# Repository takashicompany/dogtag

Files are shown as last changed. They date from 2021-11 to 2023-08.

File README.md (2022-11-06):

# DogTag

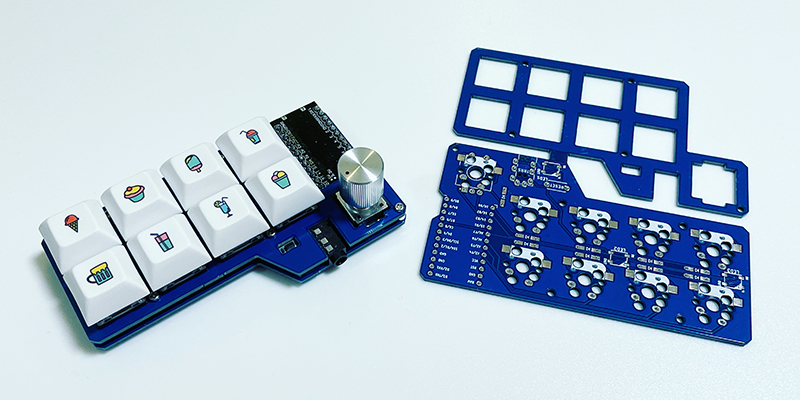
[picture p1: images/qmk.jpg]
dogtag


DogTagは9キーのコンパクトなマクロパッドです。  
100mm x 100mm 以内のPCBから組み立てます。  
リバーシブルに対応しており、2台をTRRSケーブルで接続することで分割型のマクロパッドとしても使用できます。  
その他にもロータリーエンコーダの搭載やMXソケットによるキースイッチの付け替え(ホットスワップ)も可能です。  
LEDによるアンダーグロウも可能です。  

DogTag is a compact macro pad with 9 keys.  
It is assembled from a PCB no larger than 100mm x 100mm.  
It is reversible and can be used as a split macro pad by connecting two units with a TRRS cable.  
Other features include a rotary encoder and MX sockets for hot-swapping of keyswitches.  
LED underglow is also available.  




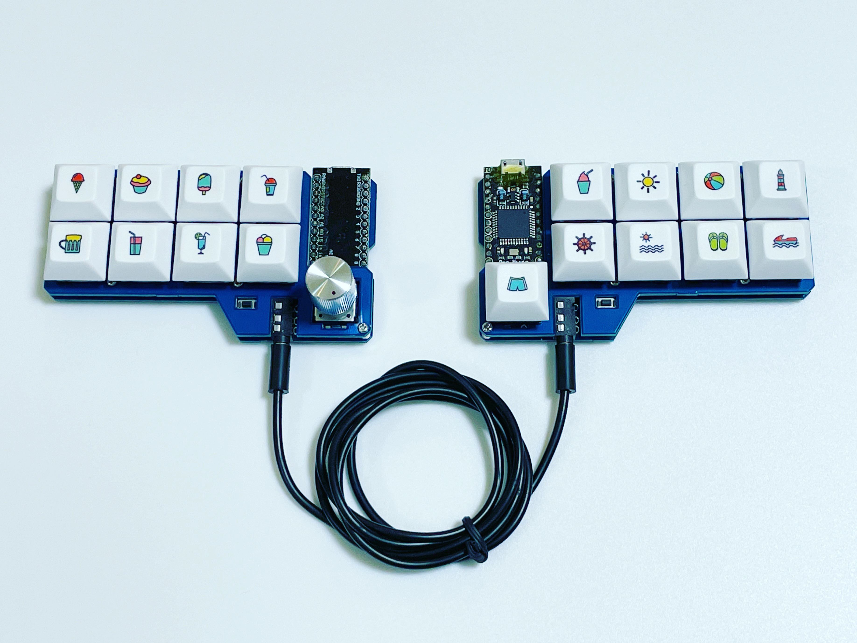
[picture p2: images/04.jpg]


## 必要な部品

### キットに同梱されているもの
|部品|個数|備考|
|:--|:--|:--|
|PCB|1|リードタイプと表面実装のダイオードに対応。|
|ダイオード（リードタイプ)|9||
|m2スペーサー(3.5mm)|5||
|m2ネジ(3mm)|10||
|リセットスイッチ|1||
|TRRSソケット|1||
|滑り止めシール|4||

### 別途用意するもの
|部品|個数|備考|
|:--|:--|:--|
|キースイッチ|9|Cherry MX互換のもの。|
|キーキャップ|9|全て1u。Chery MX互換のもの。|
|Pro Micro|1||
|USBケーブル|1|Pro MicroとPCを接続します。|

### オプション
|部品|個数|備考|
|:--|:--|:--|
|コンスルー|2|Pro Microに取り付けます。|
|MXソケット|9|キースイッチの付け替えが可能になります。|
|ロータリーエンコーダ|1|親指に近いキーにロータリーエンコーダを取り付けることができます。
|LED(SK6812MINI-E)|4|キーボードが光ります。|

## 組み立て方
alt設定 (https://www.youtube.com/watch?v=5uZxdYJqcw4)

以下の組み立て方は左手用になります。
右手側の場合は基板を裏返して組み立ててください。

### 1. トッププレートとPCBを切り離す

トッププレートとPCBが結合しているので、これを切り離します。  
(場合によっては切り離し済みのケースがあります。)  
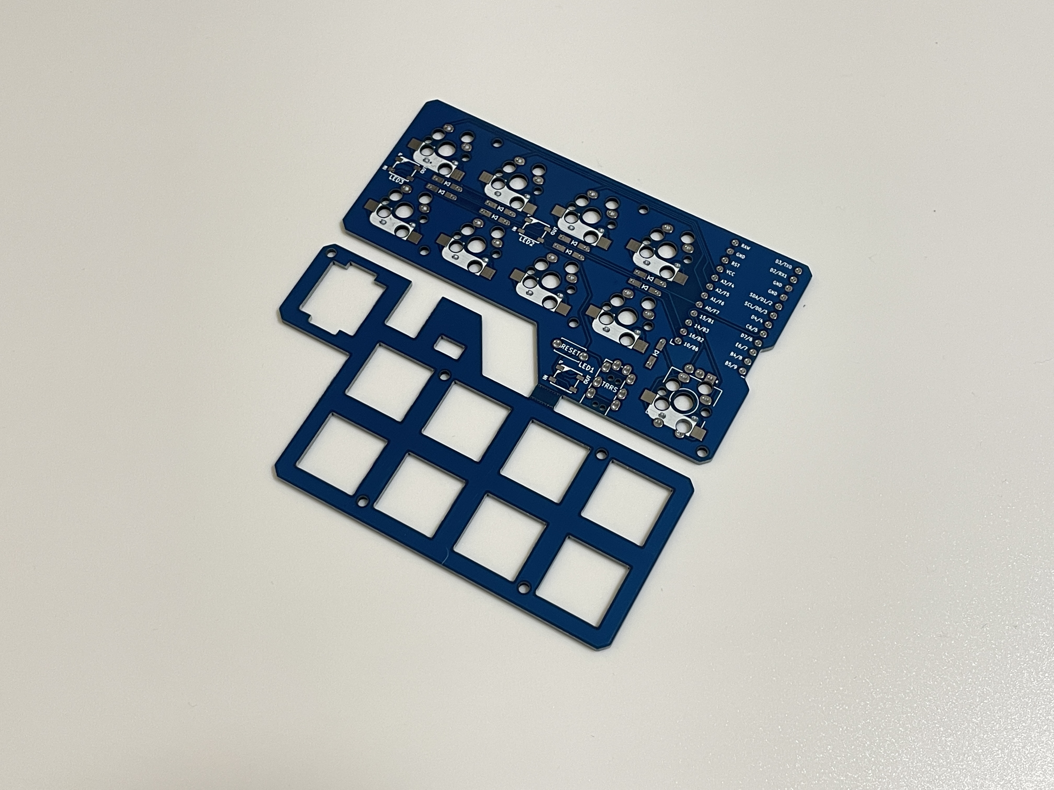
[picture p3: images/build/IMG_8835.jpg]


基板を接続部の折れ線に沿って曲げると切り離せます。  
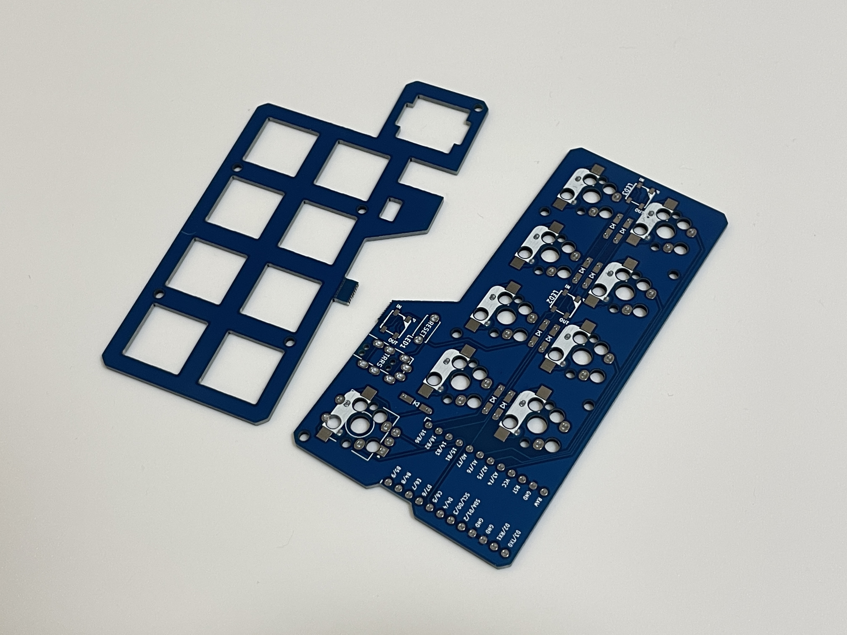
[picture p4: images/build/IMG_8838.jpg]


残った接続部分はペンチなどで折ると取りやすいです。  
折った場所をヤスリがけすると仕上がりがキレイになります。  
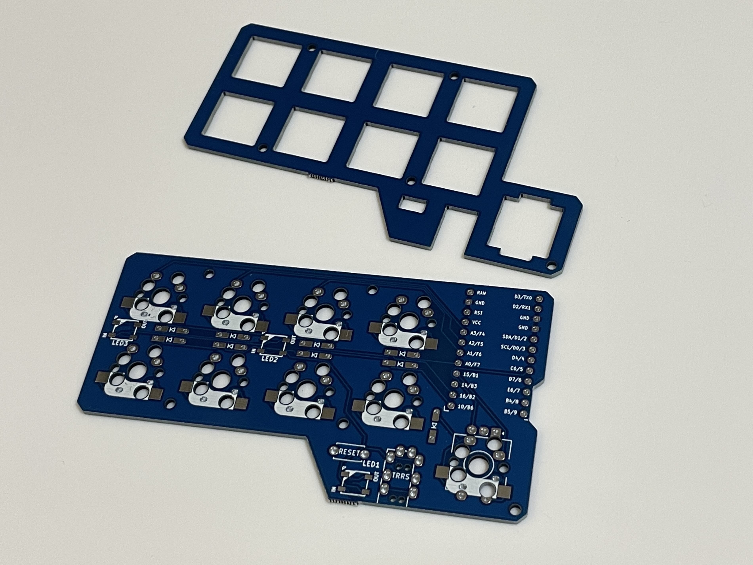
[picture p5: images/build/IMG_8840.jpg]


### 2. ダイオードをはんだ付けする  

ダイオードを取り付けます。  
余談ですが、ダイオードは電流の向きを制御する役割があります。  
自作キーボードでは主にキーが同時に押されたことを検知する役割があります。  
以上のことは知らなくても当キーボードは完成させられますのでご安心ください🙏  
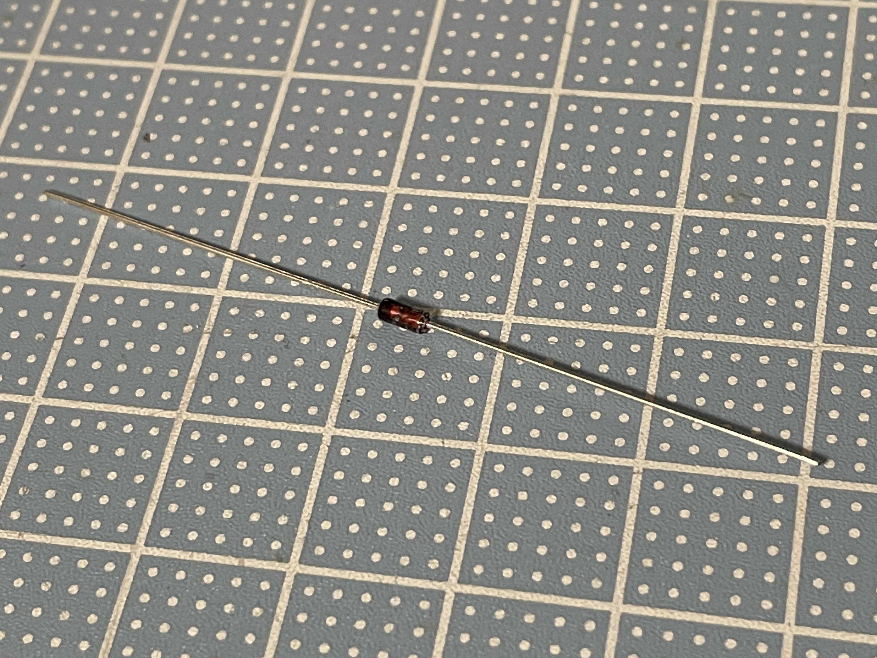
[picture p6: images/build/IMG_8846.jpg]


ダイオードが基板のはんだ付け穴に入るように足を曲げます。  
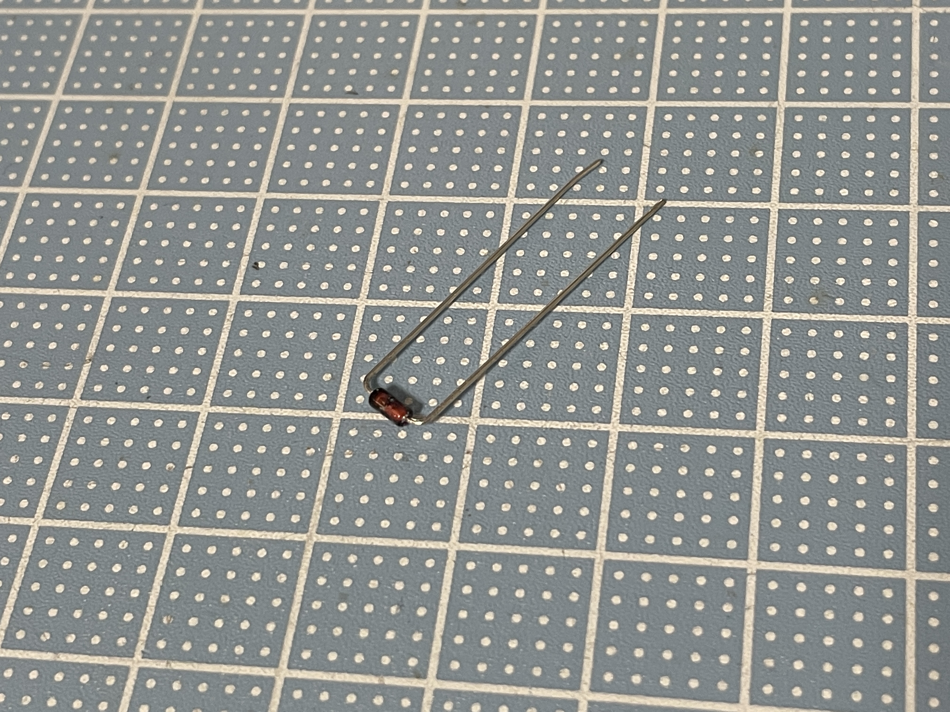
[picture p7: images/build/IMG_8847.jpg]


ダイオードをはんだ付け穴に挿します。  
ダイオードの端の黒い線が、基板の矢印(|◁)側になるようにPCBに挿します。
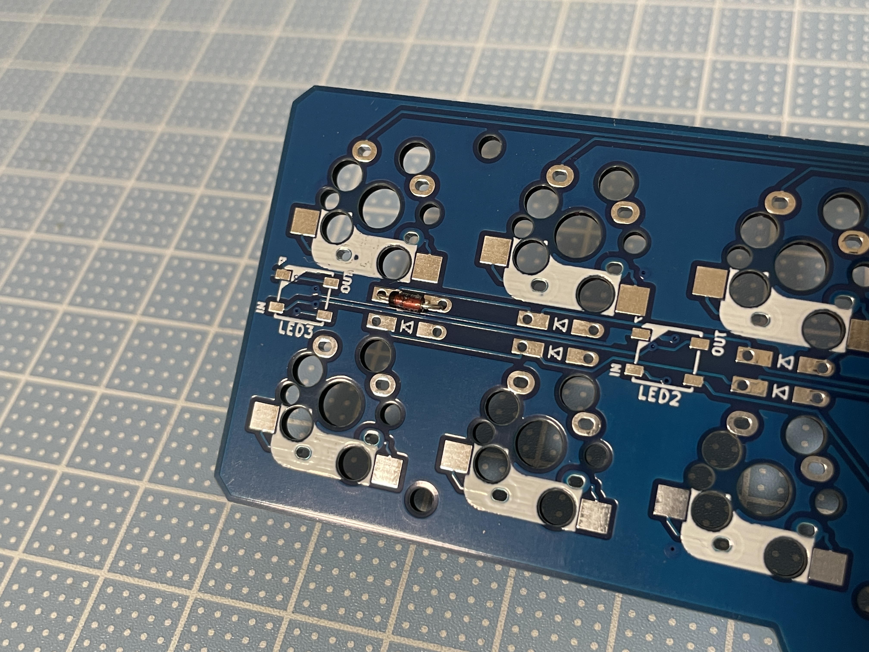
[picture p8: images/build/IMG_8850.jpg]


はんだ付けをするために基板を反対側にします。  
この時、ダイオードの足を少し開くとPCBから抜けづらくなります。  
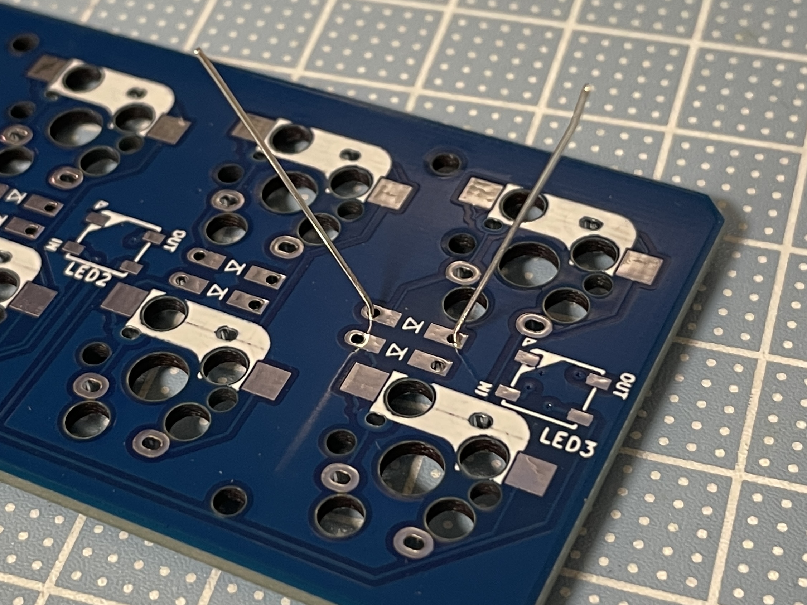
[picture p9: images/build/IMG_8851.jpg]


はんだ付けを行います。  
はんだ付けがはじめての方は[こちら](https://www.youtube.com/watch?v=iCJXT3d4140)の動画を参考に進めるとスムーズに行くかと思います。  
(難しそうなイメージがありますが、要はくっついていれば良いのです)

はんだ付けが済んだら、ニッパーで足を切ります。  
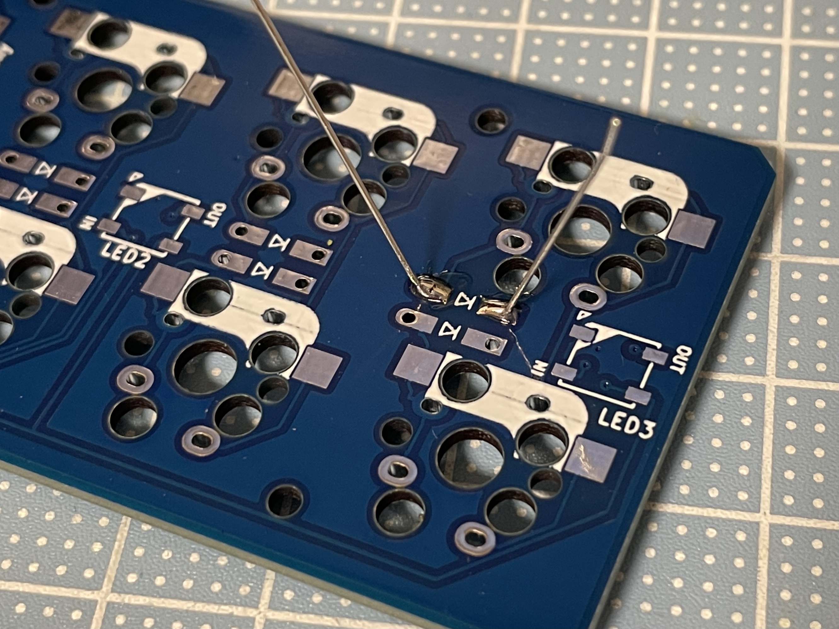
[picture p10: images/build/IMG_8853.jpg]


合計9箇所をはんだ付けします。  
**ダイオードの向きが写真と異なっていないかを確認してください。**
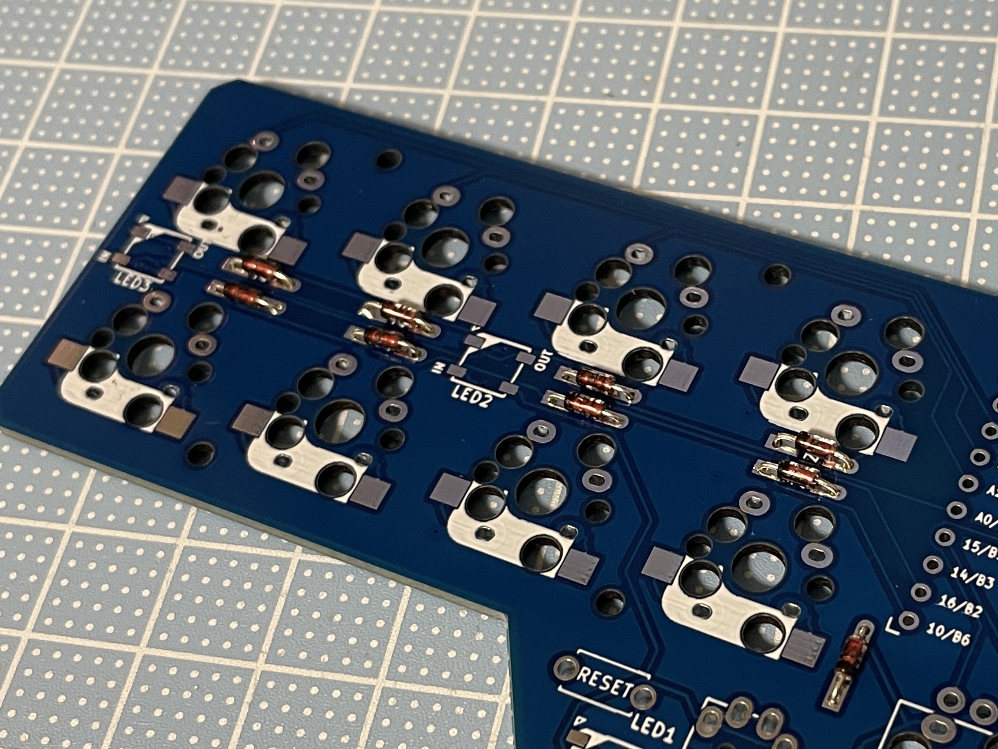
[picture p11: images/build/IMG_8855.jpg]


### 3. リセットスイッチの取り付け

リセットスイッチはファームウェアを書き込む際などに使用します。  
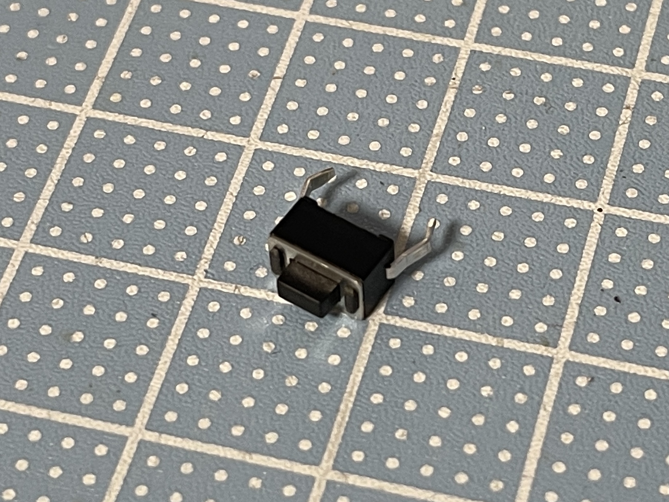
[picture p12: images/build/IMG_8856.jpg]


取り付け位置はキーボードの手前の「RESET」の印刷がされている箇所です。  
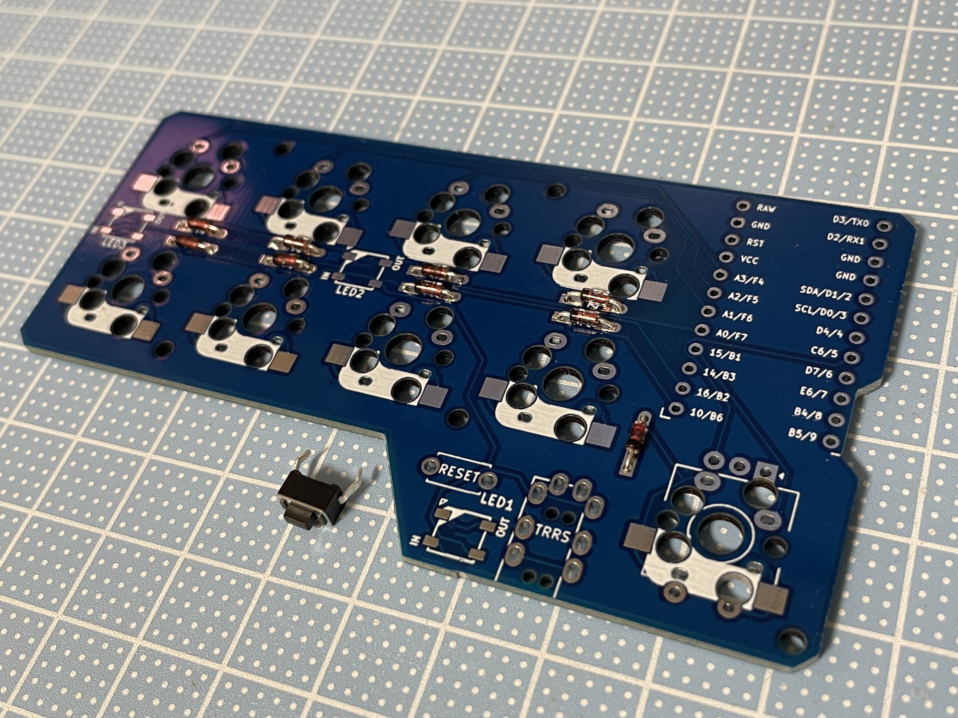
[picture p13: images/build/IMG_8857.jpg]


穴にリセットスイッチの足を挿し込みます。  
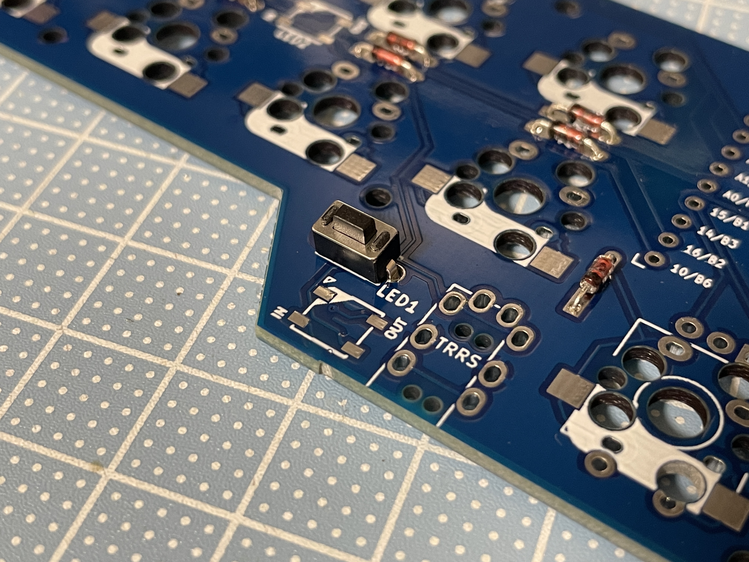
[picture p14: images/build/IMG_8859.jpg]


基板をひっくり返してリセットスイッチの足が穴から出ていることを確認します。   
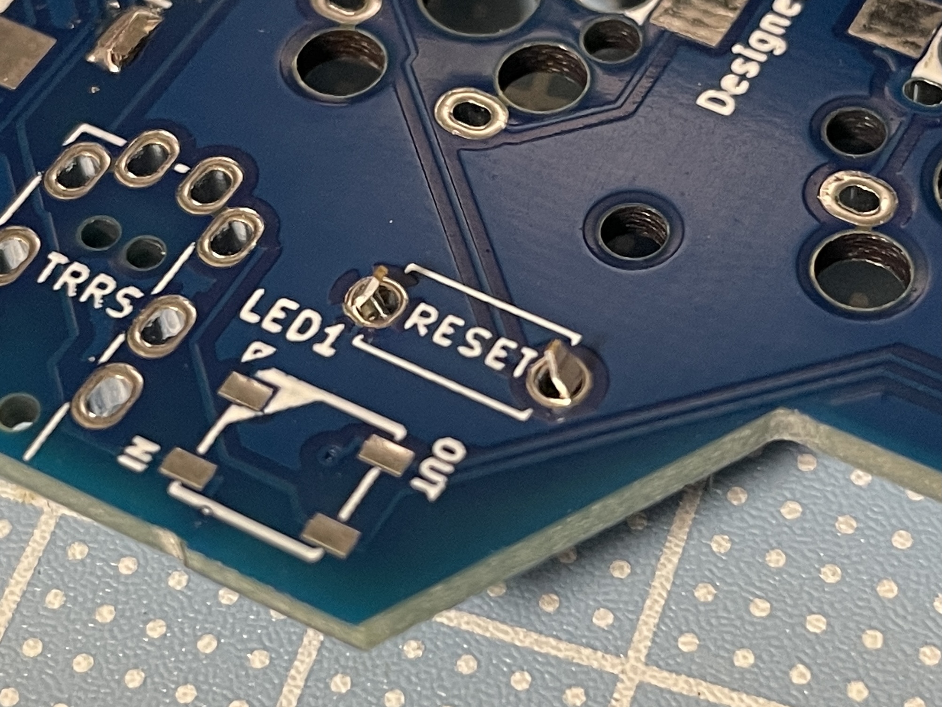
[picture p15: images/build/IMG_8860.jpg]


はんだ付けを行います。  
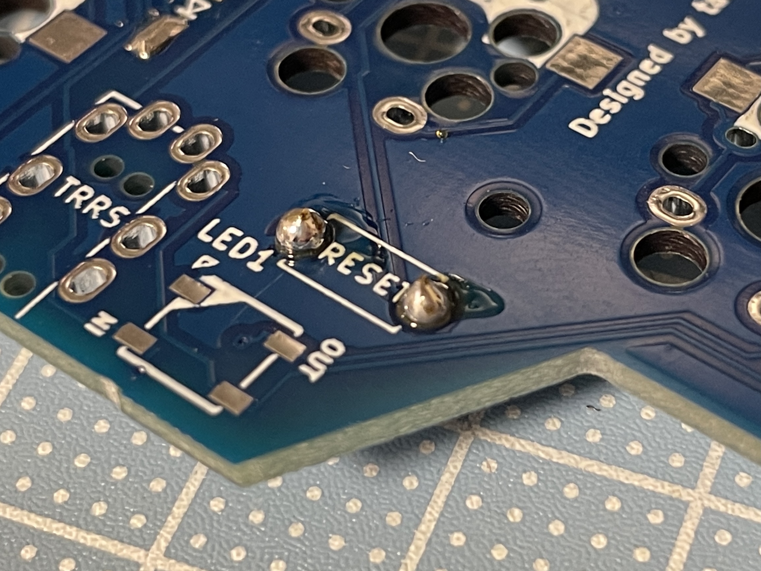
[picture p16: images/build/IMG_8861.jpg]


はんだ付けを済ませたらニッパーなどではんだ付け部分を切り取り、可能な限り平らにするとキーボードが安定しやすくなります。  
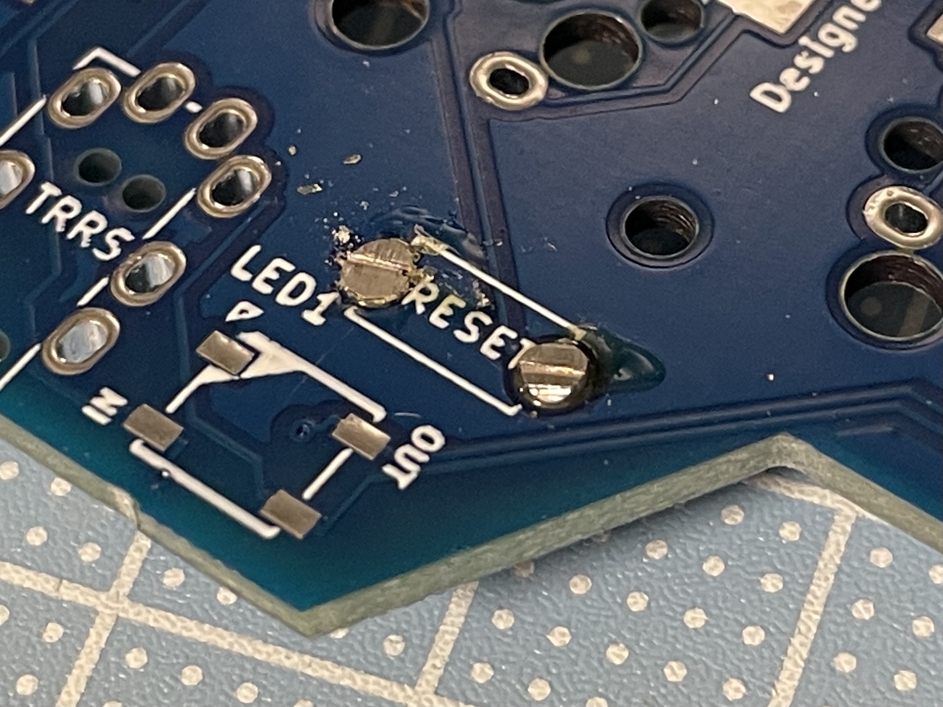
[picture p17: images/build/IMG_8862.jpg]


### 4. TRRSソケットの取り付け

TRRSソケットは、分割キーボードとして利用する場合にキーボード同士を繋げるために使います。  
単体で使う場合は使用しませんが、気が変わって両手分欲しくなっても良いように取り付けましょう笑  
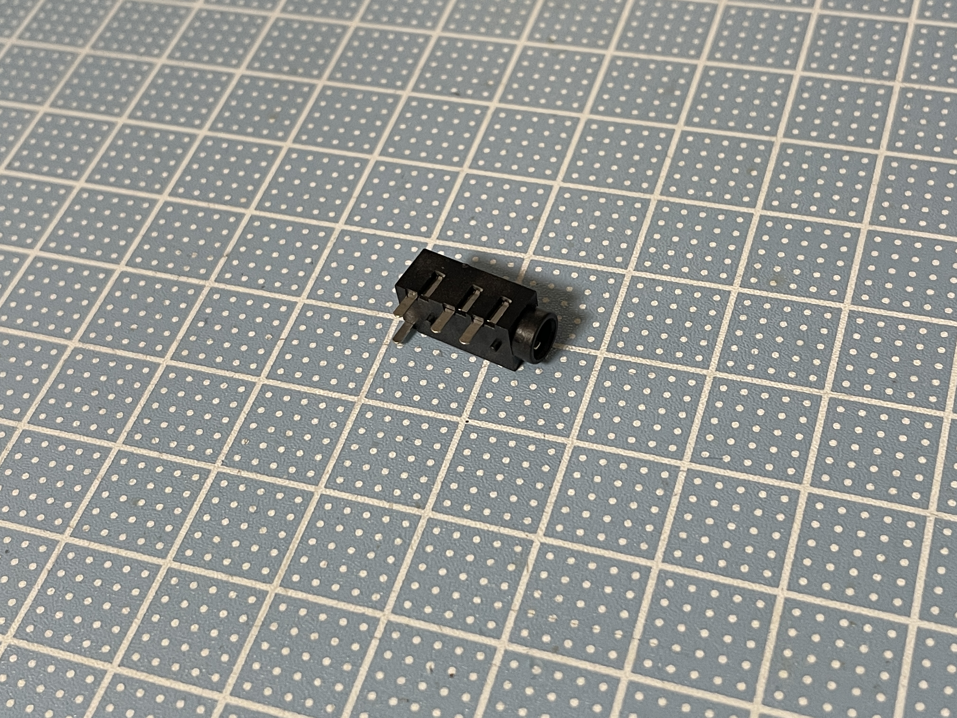
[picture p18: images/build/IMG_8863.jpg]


取り付け位置は、基板手前側の「TRRS」と印刷されている箇所です。
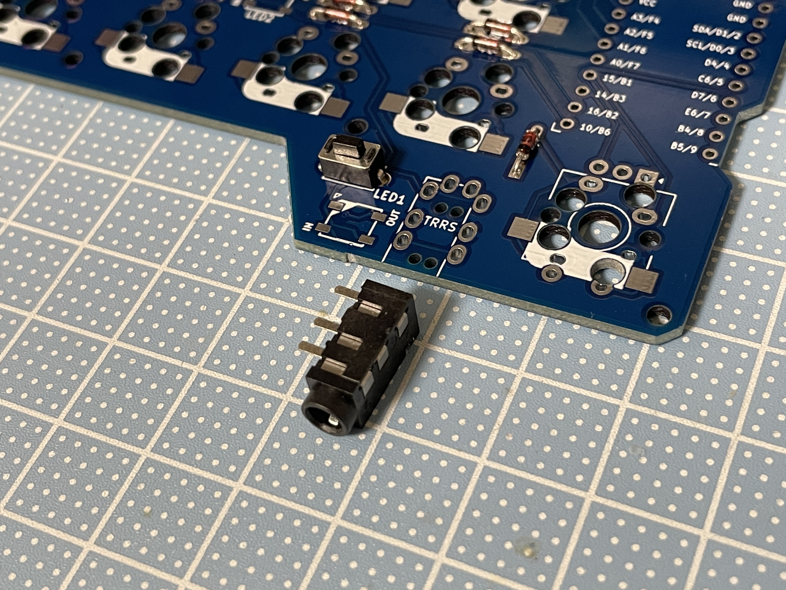
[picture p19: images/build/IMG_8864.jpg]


穴に沿って挿し込みます。  
いくつか穴が余ってしまうのは、右手側で利用する際の穴です。  
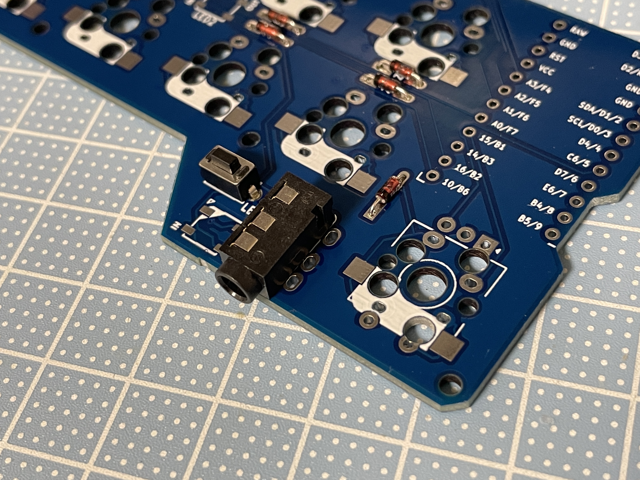
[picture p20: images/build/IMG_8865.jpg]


はんだ付けの際にひっくり返す時にTRRSソケットが抜けてしまう場合は、マスキングテープなどで固定すると良いです。  
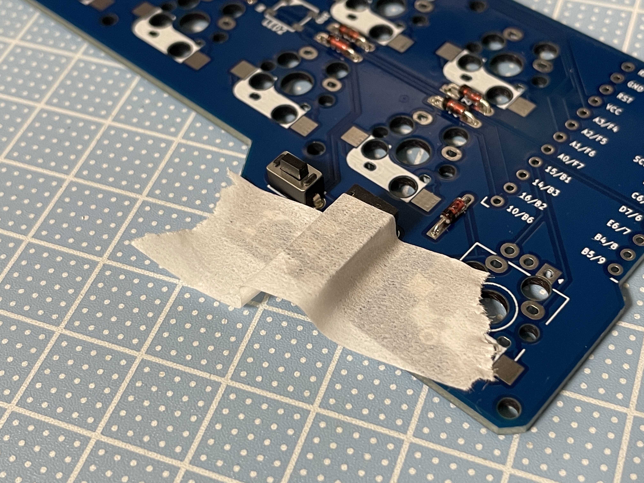
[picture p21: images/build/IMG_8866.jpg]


ひっくり返して、リセットスイッチと同様にはんだ付けを行います。  
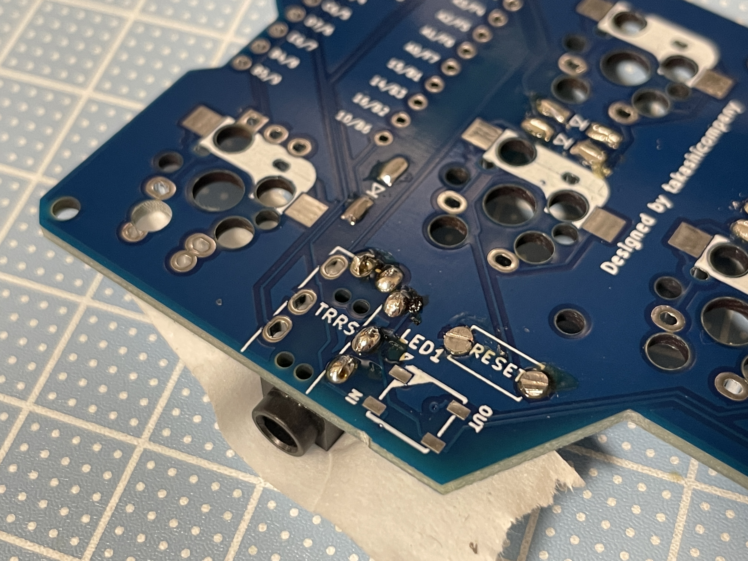
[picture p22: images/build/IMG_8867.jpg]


### 4.5 LEDの取り付け

(LEDを取り付けない方は、この項目はスキップして問題ありません。)

Rev2以降の基板ではSK6812MINI-Eを取り付け、DogTagを光らせることができます。

下の写真と同じく、PCBの底面に取り付けることで表側へLEDの光が届くようになります。  


### 5. トッププレートの取り付け  

トッププレートを取り付けます。  
**取り付けるPro Microによっては、トッププレートと干渉してしまう場合があるので、必要に応じてヤスリなどで削るとスムーズに取り付けられるかと思います。**  
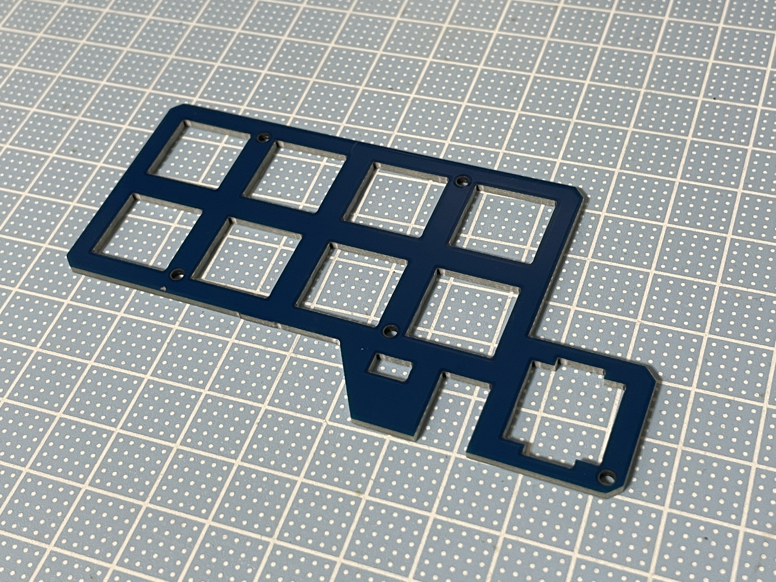
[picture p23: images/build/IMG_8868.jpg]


ネジが2種類同梱されている場合は、左の頭が小さいネジはトッププレート側(表側)、右の頭が大きいネジはボトムプレート側(底面側)に使用します。  
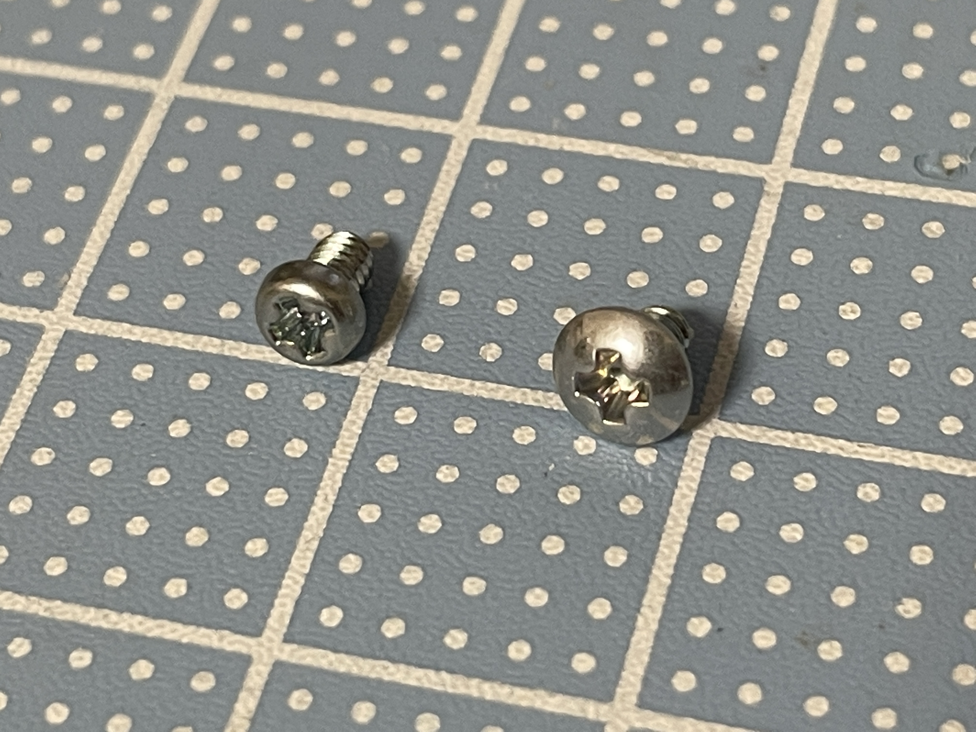
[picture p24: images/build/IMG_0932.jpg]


取り付けにはネジとスペーサーを使用します。  
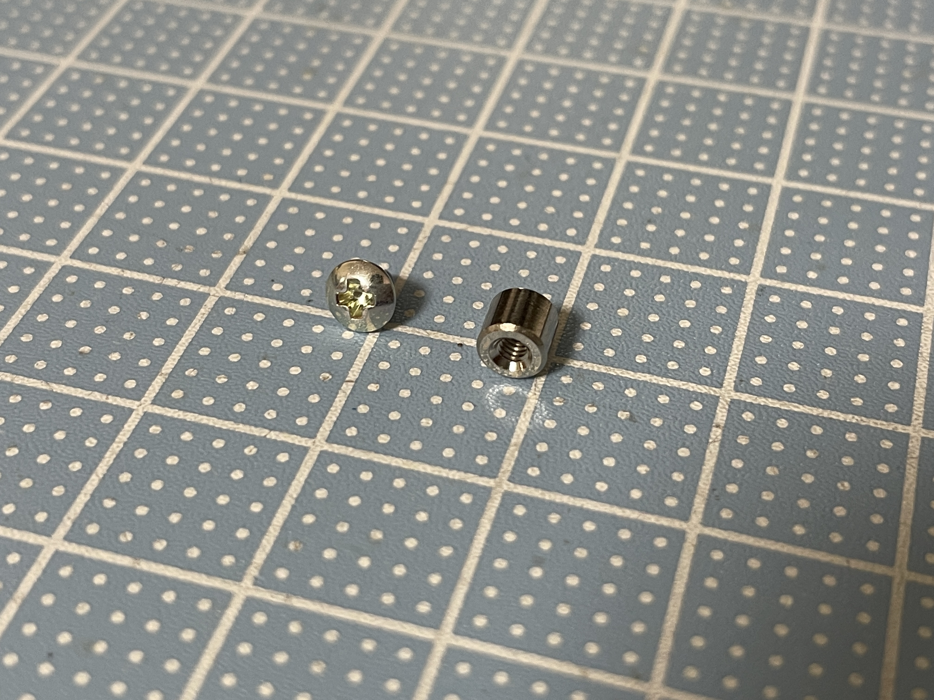
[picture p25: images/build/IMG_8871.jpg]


赤丸の位置に、スペーサーをネジで固定します。  
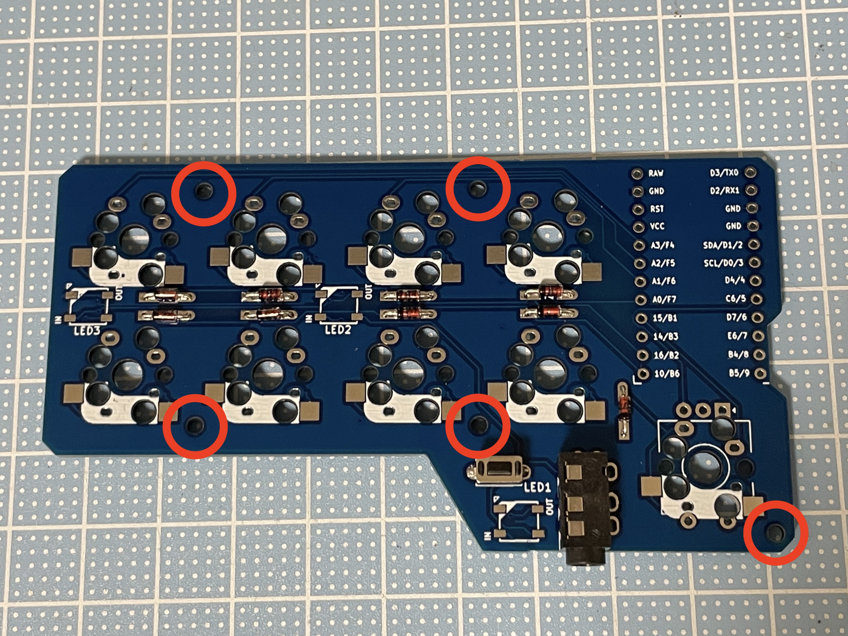
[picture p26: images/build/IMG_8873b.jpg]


このように5箇所にスペーサーを取り付けます。  
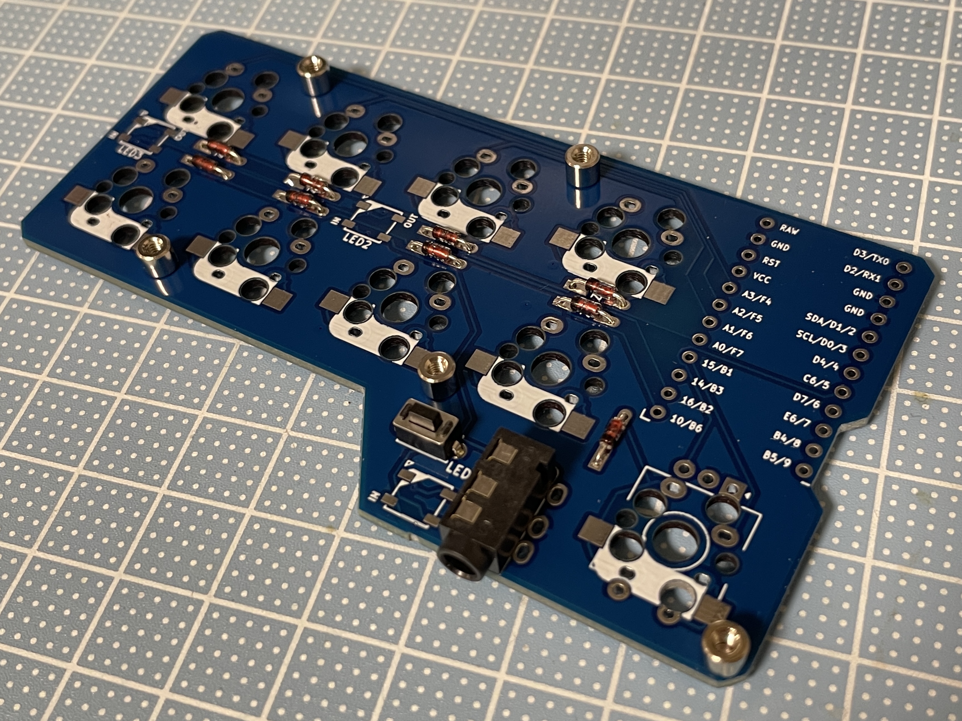
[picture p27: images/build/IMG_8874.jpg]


最後にトッププレートを取り付けます。  
スペーサーとトッププレートをネジで固定します。  
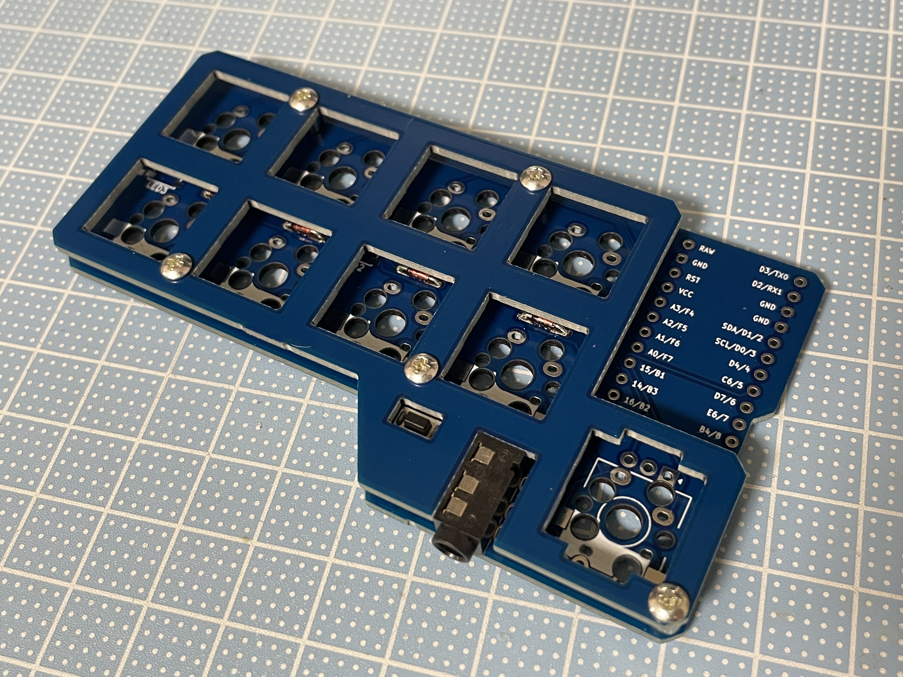
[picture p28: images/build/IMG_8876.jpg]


### 6. Pro Microの取り付け。

Pro Microはキーボードの頭脳となる部分です。  
キースイッチが押されたことを検知して、PCにキーの入力を伝えます。  
Pro MicroをPCBに固定する際は[コンスル](https://shop.yushakobo.jp/products/31)ーという部品を用いるのがオススメです。  
コンスルーを使うと、Pro Microを基板から楽に取り外せるので、メンテナンスがしやすかったり、他の自作キーボードに使い回すことが容易になります。  
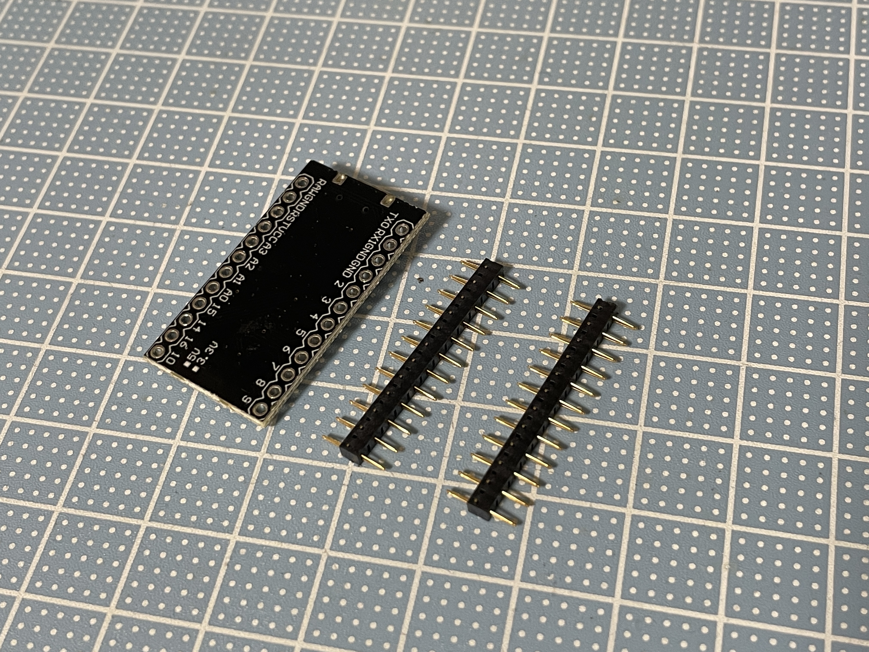
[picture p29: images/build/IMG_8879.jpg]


[コンスルーがはんだ付けされたものが遊舎工房さんで販売されている](https://shop.yushakobo.jp/products/a0500ph?variant=37665498497185)ので、難しそう…と感じた方は購入するのもアリだと思います。

Pro Microにコンスルーを挿します。  
左手側の場合はPro Microのチップなどが配置されている側が裏になるようにしてください。  
(右手側の場合は逆にチップ側が表になるようにしてください。)  
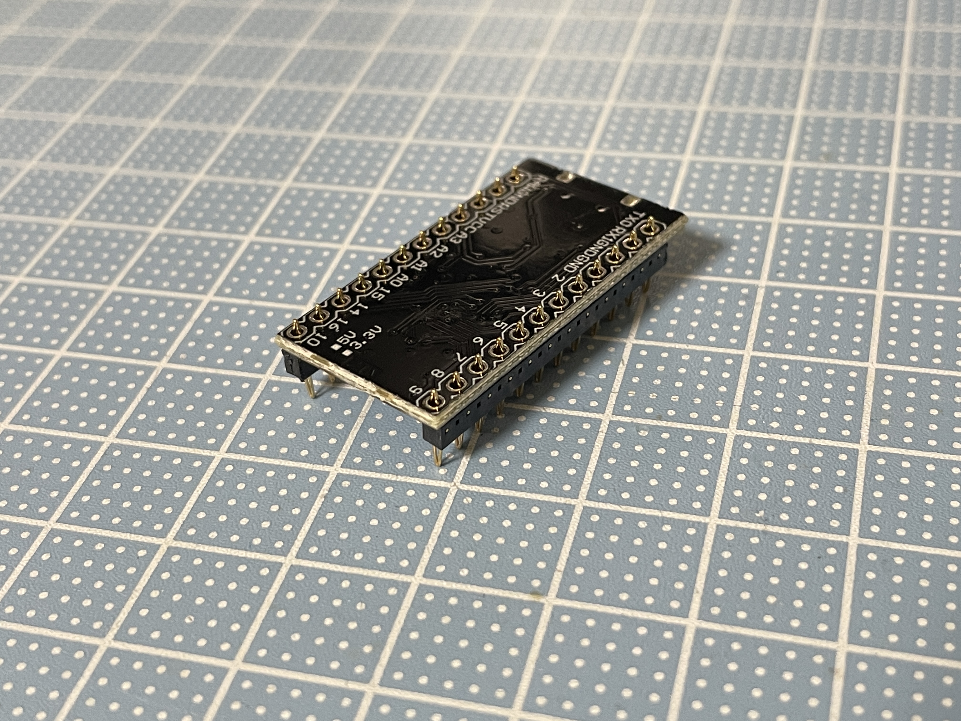
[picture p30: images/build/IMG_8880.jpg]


コンスルーでPro MicroとPCBを接続します。  
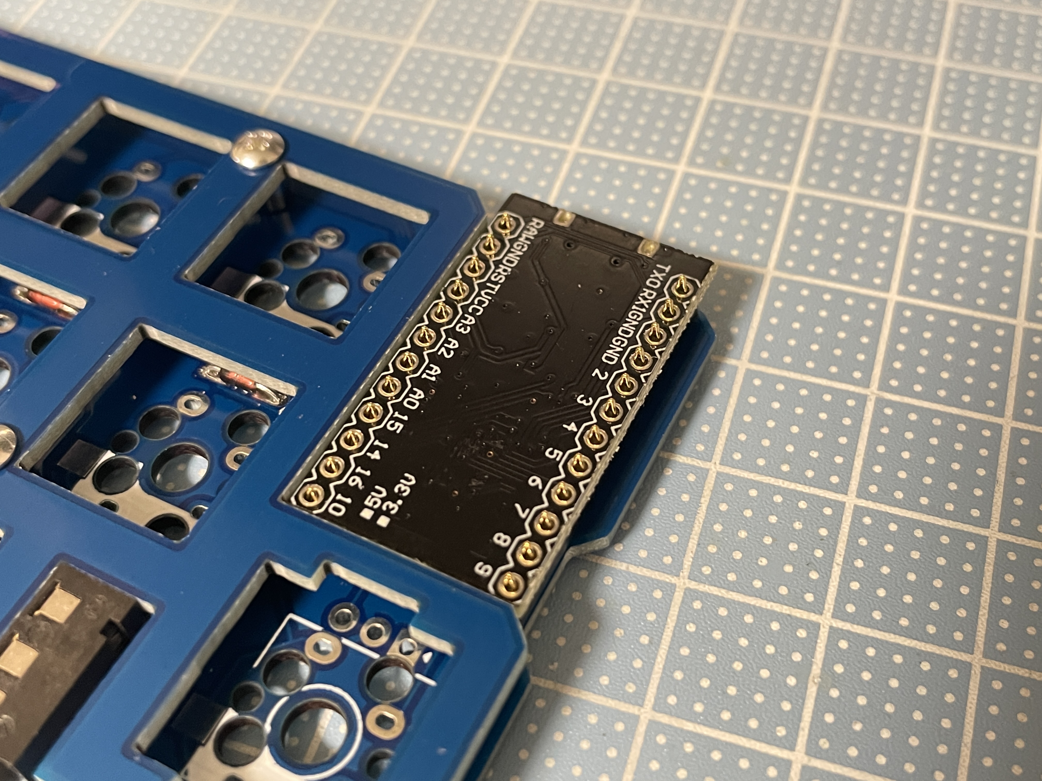
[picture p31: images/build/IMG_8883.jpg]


Pro Microをはんだ付けします。  
トッププレートとPro Microがぶつかってしまうことがあるので、正しく挿されているか側面から確認するとミスを避けられます。 
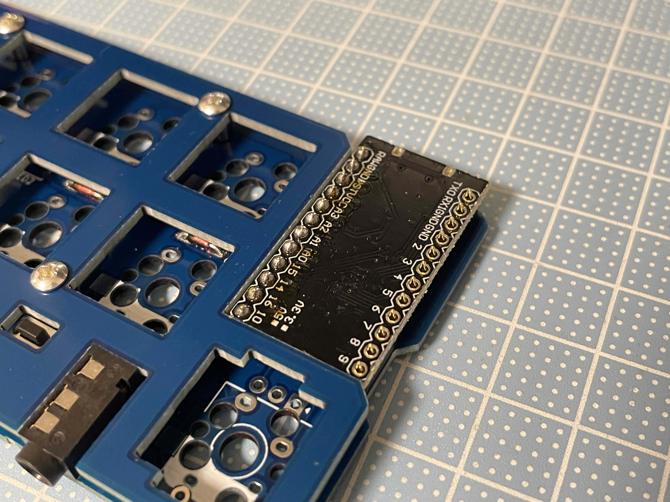
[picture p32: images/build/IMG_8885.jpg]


全ての端子をはんだ付けできたら完了です。  
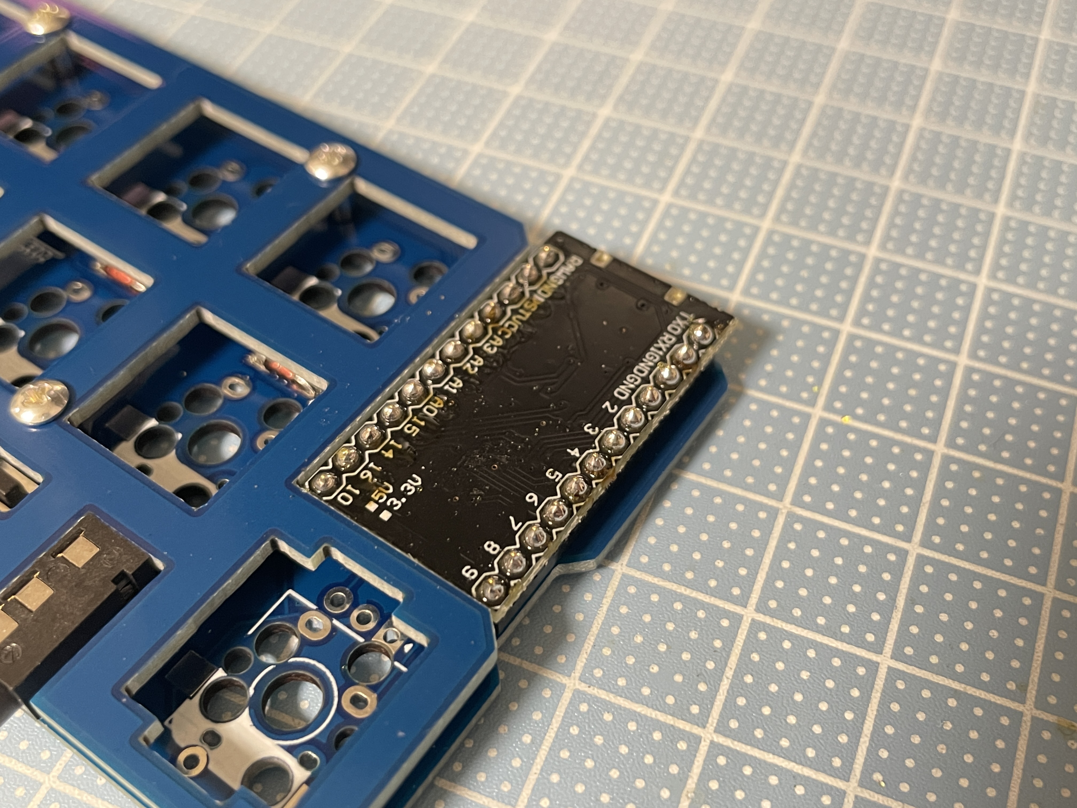
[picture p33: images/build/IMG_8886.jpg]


### 7. キースイッチのはんだ付け

キースイッチを取り付けます。  
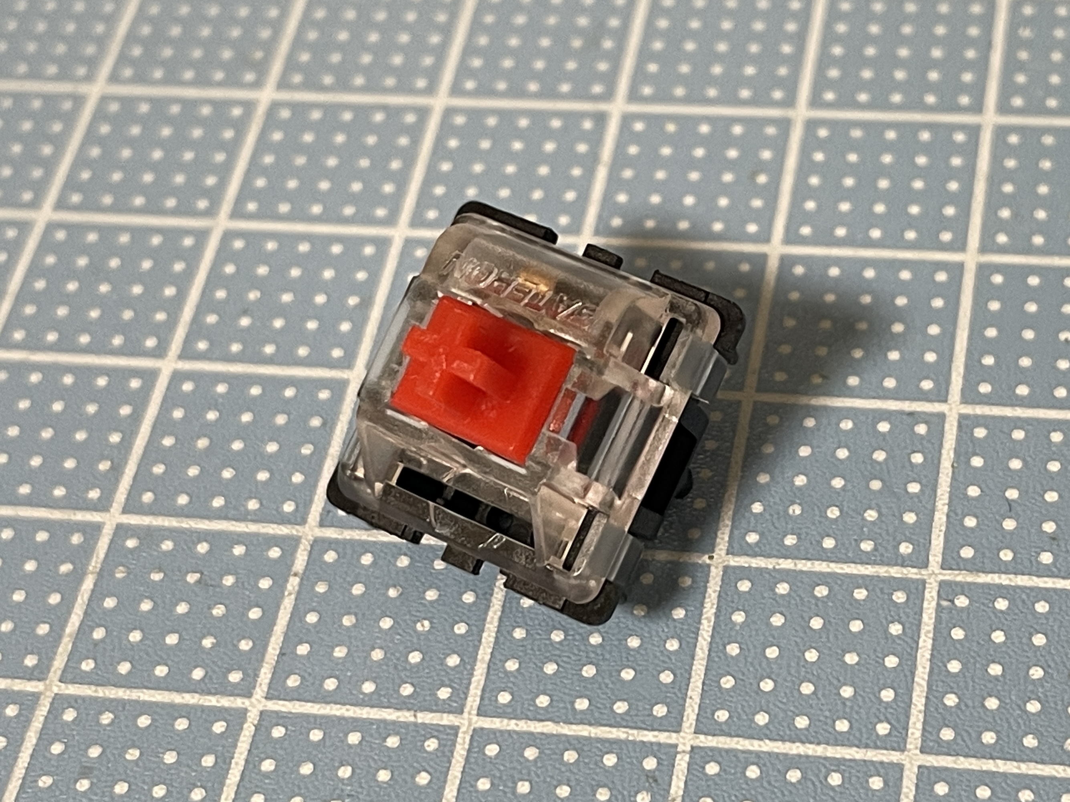
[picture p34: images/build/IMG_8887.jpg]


キースイッチの取り付け方は2種類あります。

#### a. キースイッチを直にはんだ付けする場合

キースイッチをトッププレートに挿し込みます。  
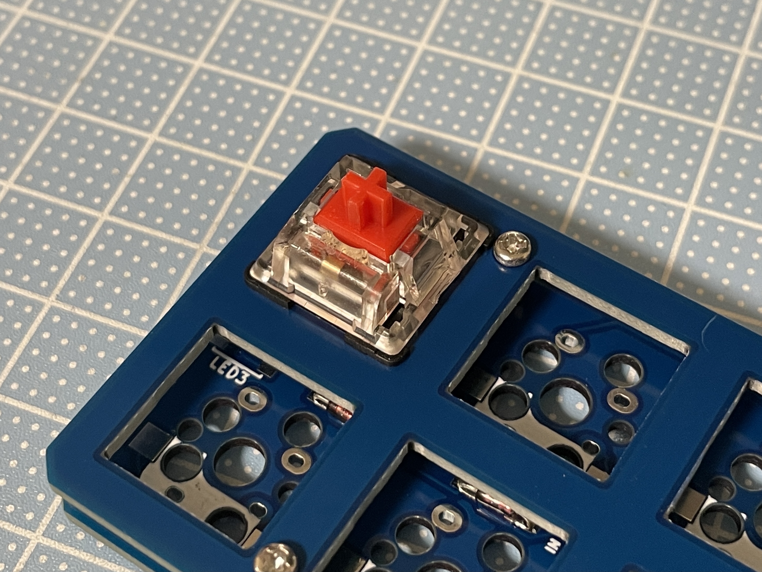
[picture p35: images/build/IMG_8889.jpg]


キースイッチの足がはんだ付け穴(周りが銀箔になっている)から出ていることを確認します。　　
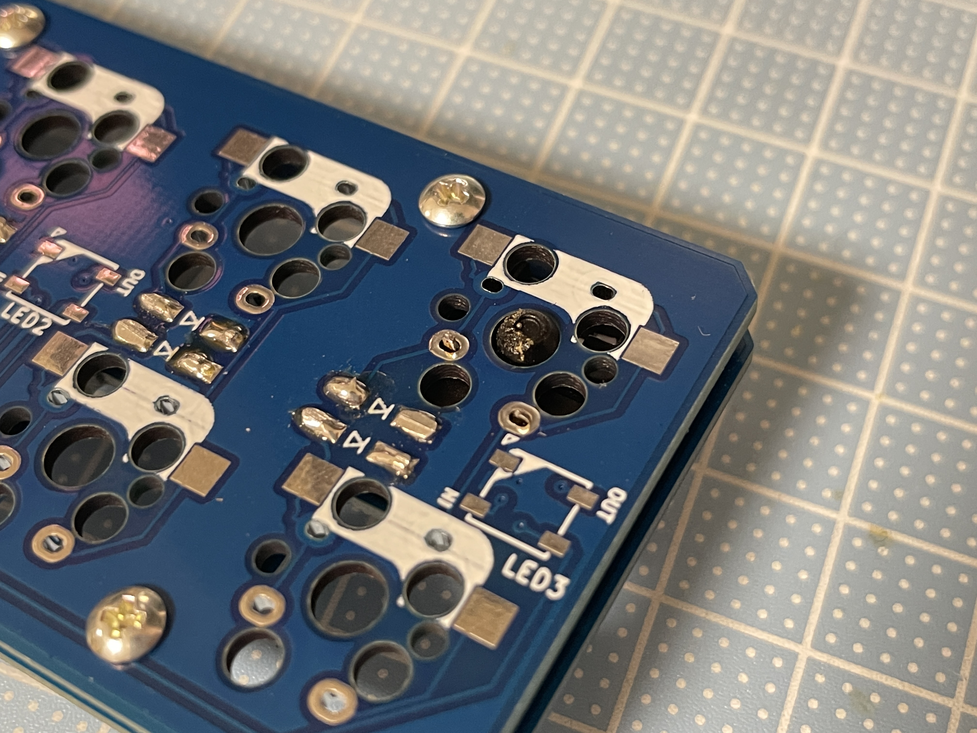
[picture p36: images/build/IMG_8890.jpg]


キースイッチの足をはんだ付けします。  
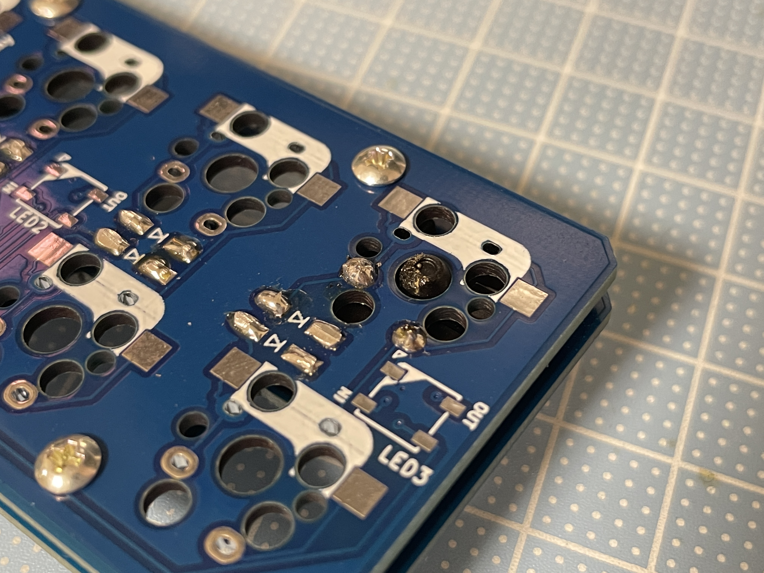
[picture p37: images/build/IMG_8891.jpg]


#### b. MXソケットを使う場合  

MXソケットをPCBにはんだ付けし、キースイッチをMXソケットで固定する方式です。  
手間が増えますが、キースイッチを付け替えられることがメリットです。  
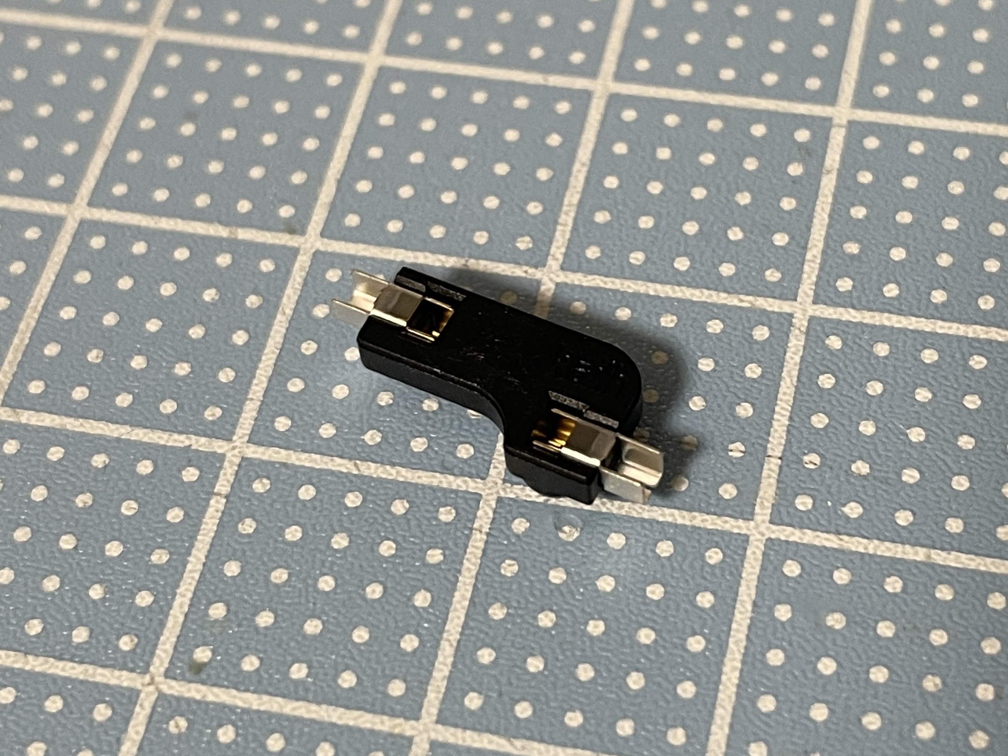
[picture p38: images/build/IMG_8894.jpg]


MXソケットのプリントのうち片方のはんだ付け箇所に事前にはんだを載せておきます。(予備ハンダというそうです。)  
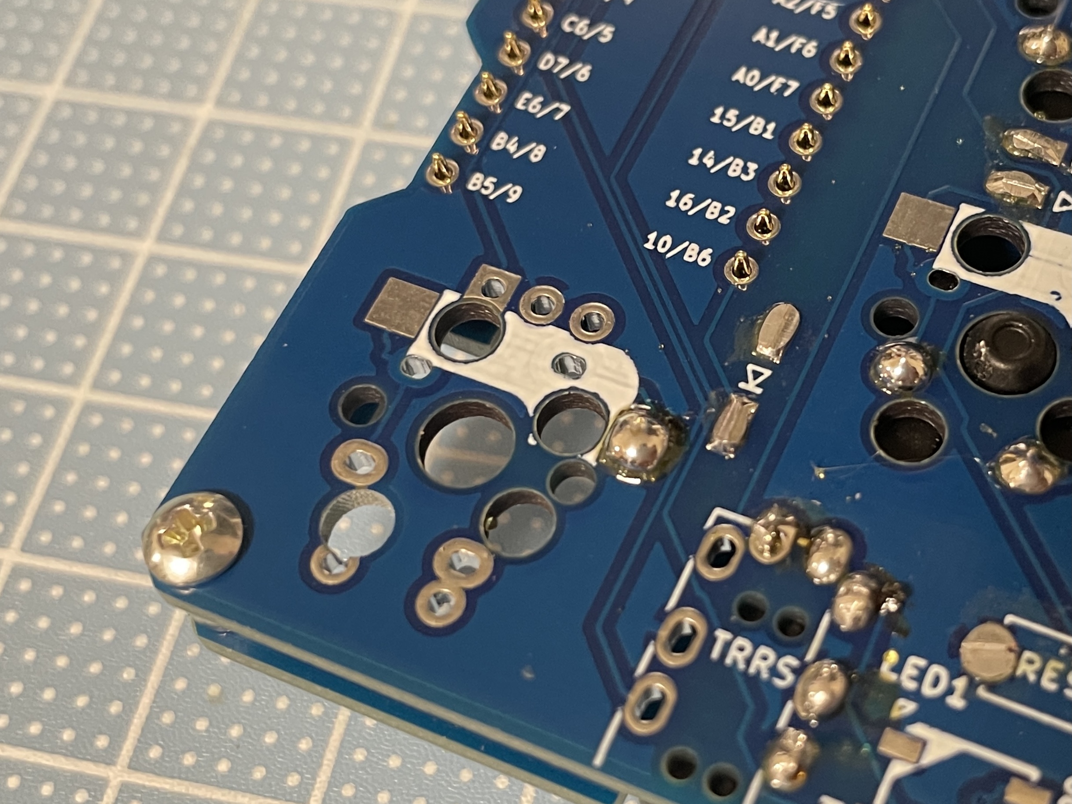
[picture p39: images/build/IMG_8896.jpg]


MXソケットをピンセットで抑えながら、予備ハンダを溶かしながらMXソケットの片方をはんだ付けします。  
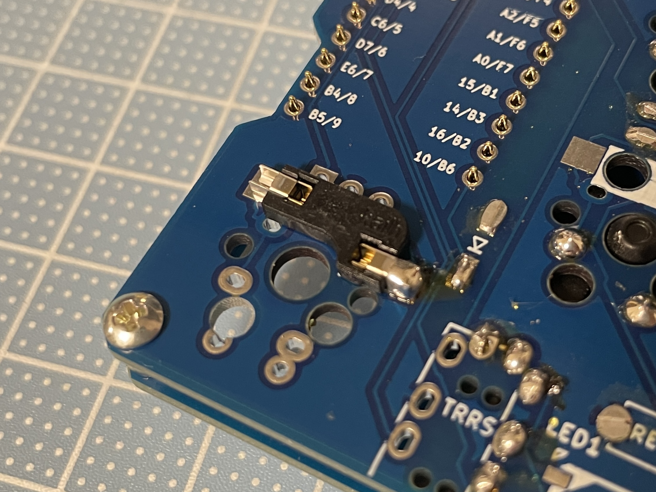
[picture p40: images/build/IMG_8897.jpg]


もう一方のはんだ付け箇所もはんだ付けして完了です。  
表面からキースイッチをMXソケットに挿し込みます。  


9箇所にキースイッチを挿し込めば完了です。  


### 8. ゴム足を付ける

ゴム足をつけて完成です。  


底面に取り付けます。  


### 9. キーキャップを取り付ける

最後にキーキャップを取り付けて完成です。  


### 10. ファームウェアの書き込み

ファームウェアは[Remap](https://remap-keys.app/catalog/1vSyBflE9L18u1AavBH4/firmware)から書き込めます。  
キーボードをPCに接続し、GoogleChromeで上述したサイトを開き「Flash」をクリックするとファームウェアの書き込みが始まります。  


Remapでのキーマップの書き換え方は[こちら](https://salicylic-acid3.hatenablog.com/entry/remap-manual)。

QMKへのプルリクエストは下記になります。
https://github.com/qmk/qmk_firmware/pull/15259

### 11. 自慢する
完成しましたら、ぜひSNSなどに写真を投稿頂ければと思います。  
Twitterのハッシュタグは`#DogTagMacroPad`を付けていただけば幸いです。  
キットを組み立てた感想や、キーボードを使った所感などをお待ちしております！  

また、毎週日曜日の１9時より実施されている[#KEEP_PD](https://twitter.com/hashtag/KEEB_PD?f=live)に投稿頂くこともオススメです。  
開催の告知は[@KEEB_PD](https://twitter.com/KEEB_PD)にて行われております。

ご不明な点などございましたら、[@takashicompany](https://twitter.com/takashicompany)にメンションやDM頂ければと思います！

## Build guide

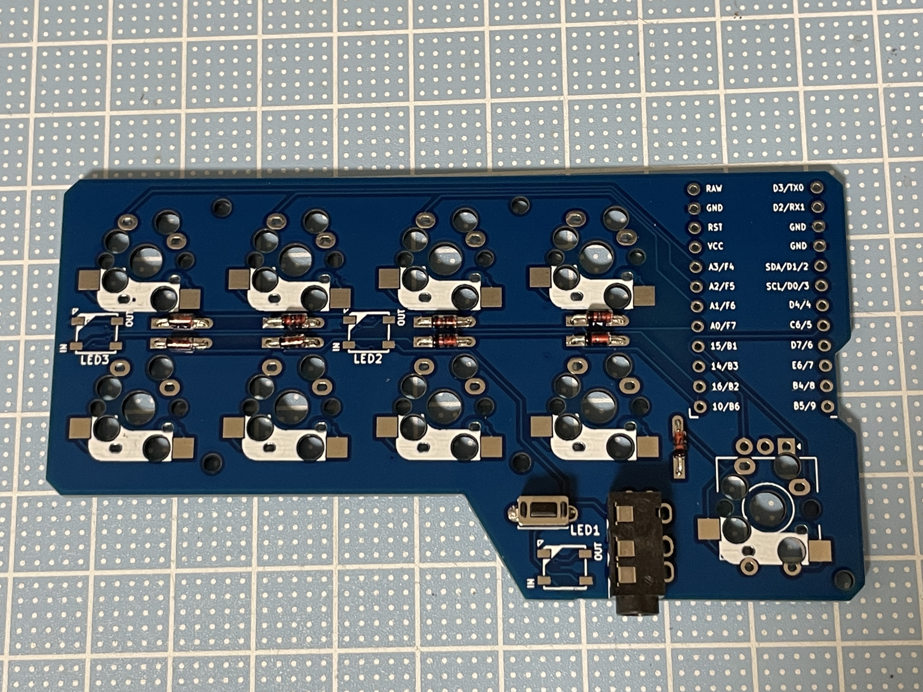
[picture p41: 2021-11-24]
images/build/IMG_8873.jpg

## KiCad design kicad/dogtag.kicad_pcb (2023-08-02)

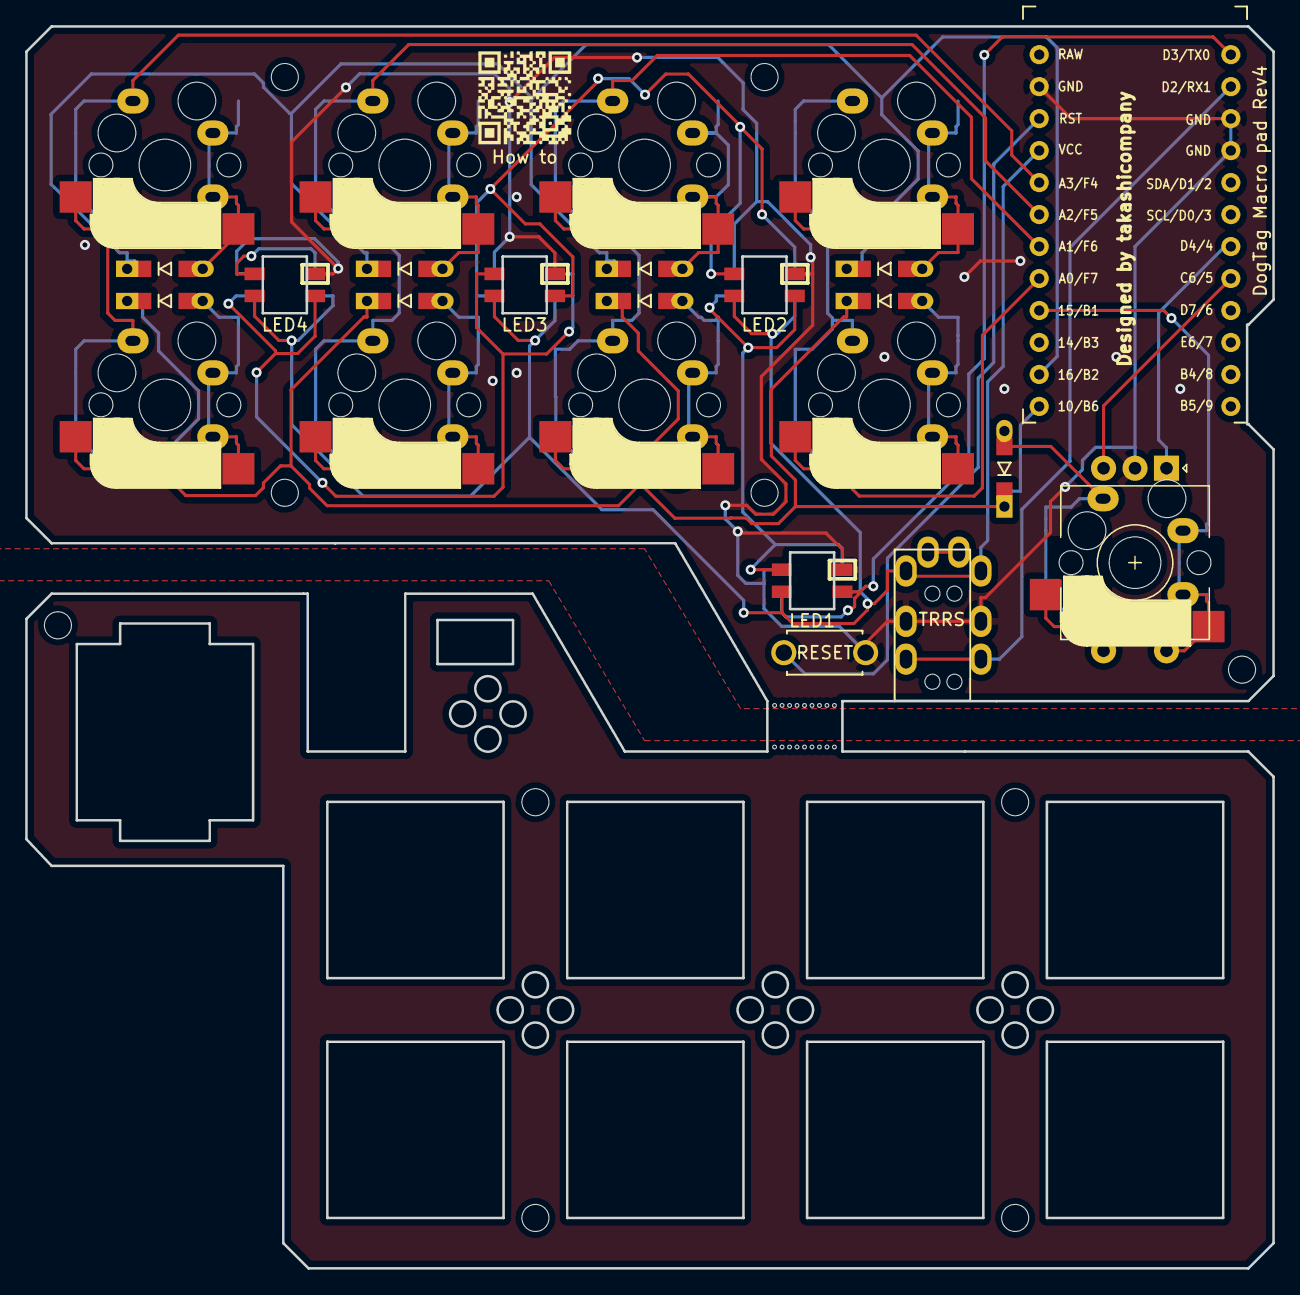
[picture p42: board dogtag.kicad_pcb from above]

Board: 2 copper layers, 99.0 x 98.6 mm, 42 parts (0 on the bottom side), 26 nets.

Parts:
BT00, BT01: Breakaway_Tabs
D1, D2, D3, D4, D5, D6, D7, D8, D9: DIODE; D3_TH_SMD_v2_Reversible
Hole00, Hole01, Hole02, Hole03, Hole04, Hole05, Hole06, Hole07, Hole08: Val**; M2_Hole
J1: MJ-4PP-9
LED1, LED2, LED3, LED4: YS-SK6812MINI-E; SK6812MINI_bg_reversible
LH1, LH2, LH3, LH4: LED_Hole-4
RESET_SW1: SW_Push; ResetSW
RH1: ResetSW_HOLE
Ref**: Val**; M2_Hole
SW1, SW2, SW3, SW4, SW5, SW6, SW7, SW8: SW_Push; CherryMX_TH_Hotswap_Reversible_v2
SW9: RotaryEncoder_Switch; CherryMX_TH_Hotswap_Reversible_RotaryEncoder_EC11_v3
U1: ProMicro; ProMicro_v3.5_print-inside

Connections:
GND: J1.C, LED1.3, LED2.3, LED3.3, LED4.3, RESET_SW1.2, SW9.C, U1.3, U1.4, U1.23
unnamed: D1.2, SW1.2
unnamed: D2.2, SW2.2
unnamed: D3.2, SW3.2
unnamed: D4.2, SW4.2
unnamed: D5.2, SW5.2
unnamed: D6.2, SW6.2
unnamed: D7.2, SW7.2
unnamed: D8.2, SW8.2
unnamed: D9.2, SW9.S1
unnamed: LED1.2, LED2.4
unnamed: LED2.2, LED3.4
unnamed: LED3.2, LED4.4
VCC: J1.D, LED1.1, LED2.1, LED3.1, LED4.1, U1.21
col1: SW1.1, SW5.1, U1.20
col2: SW2.1, SW6.1, U1.19
col3: SW3.1, SW7.1, U1.18
col4: SW4.1, SW8.1, U1.17
col5: SW9.S2, U1.16
data: J1.B, U1.2
led: LED1.4, U1.1
reset: RESET_SW1.1, U1.22
rot-a: SW9.A, U1.7
rot-b: SW9.B, U1.8
row1: D1.1, D2.1, D3.1, D4.1, U1.14
row2: D5.1, D6.1, D7.1, D8.1, D9.1, U1.13

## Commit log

2021-11-22 画像を追加
2021-11-22 qmk用の画像
2021-11-22 サマリー
2021-11-22 順番を修正
2021-11-24 必要な部品を列挙
2021-11-24 buid guide用の画像
2021-11-24 ビルドログを追加
2021-11-24 途中までだけどコミット
2021-11-24 画像を入れた
2021-11-26 ここまで出来た
2021-11-26 改行を調整
2021-11-26 ちょっと明るくした
2021-11-26 赤丸を付けたバージョン
2021-11-26 新しい画像を追加
2022-01-31 rev1のガーバーファイルを追加
2022-03-07 youtubeリンク
2022-03-26 ハッシュタグを変更
2022-05-10 add rev4 gerber
2022-09-13 デザイン
